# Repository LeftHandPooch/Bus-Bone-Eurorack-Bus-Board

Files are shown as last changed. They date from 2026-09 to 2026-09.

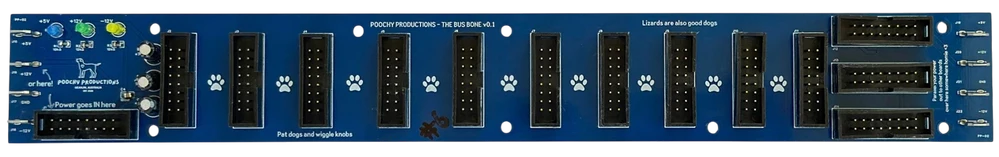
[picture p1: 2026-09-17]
PP02Hylin.webp

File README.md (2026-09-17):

# PP-02 Bus-Bone
A 14-header Eurorack passive/filtered bus-board

<p>
    
</p>

## WHY DID YOU MAKE THIS?
- Easy to build, good for practicing/learning circuit design.
- There is a great need for reliable, cheap busboards.

## WHY SHOULD I MAKE THIS?
- Aaffordable and reliable entry into the incredible world of modular.
- Ribbon cables are sketchy.
- Fully filled out supplier parts sheet so you don't have to spec anything - one-click order through JLCPCB.
- Intermediate friendly layout for those wanting to try SMD soldering.
- Lovely poochy paw prints + all the technical details on the silkscreen print.

## TECHNICAL DETAILS
- DIMENSIONS: 40mm (H) x 300mm (W) x 15mm (D)
- +12V, -12V and +5V.
- High quality PCBs with wide copper traces to accommodate high power loads.
- Spade connectors on either end to connect alternative PSUs
- Power-noise filtering caps
- 14 generously-spaced, keyed 16-pin box-headers
- Blue/Yellow/Green indicator LEDs for each power rail
- Open-source design - https://github.com/LeftHandPooch/Bus-Bone-Eurorack-Bus-Board
- Eight 3.4mm mounting holes available to mechanically secure the board to your case (3M screws/bolts and nylon washers recommended)
- Handmade in Meanjin, Australia by Brisbane’s hirsute hound, Lefthandpooch.
- 17/09/26 Built stock currently available to buy online or in-person in Brisbane @ HYLIN Devices - https://hylindevices.com.au/products/pp-02-bus-bone

## Changelog

### Bus Bone v0.1
- the original!
- drawn using EasyEda and subsequently broke the association between schematic and PCB. Darn. 
### Bus Bone v0.2
- moved components around very slightly to possibly prevent shorting of +5V rail near first header.

### Thanks and credits
My many friends and loved ones for tolerating/encouraging my passion for electronics, music and synths <3

Licensed under MIT license. 

Build and use at your own risk.

For further notes and build advice, see Basic BoM.txt

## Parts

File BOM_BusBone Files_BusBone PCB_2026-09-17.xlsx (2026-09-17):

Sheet: bom模板
 |  |  |  | Bill of Materials | BOM_BusBone Files_BusBone PCB_2026-09-17
 |  |  |  | Project Title： | PP02BusBone
 |  |  |  | Variant:
 |  |  |  | Report Time： | 2026年9月17日 13:27:15
No. | Quantity | Comment | Designator | Footprint | Value | Manufacturer Part | Manufacturer | Supplier Part | Supplier | LCSC Price | Total
 | 3 | 47uF | C1, C2, C3 | CAP-TH_BD6.3-P2.50-D1.0-FD | 47uF | ERM1HM470E11OT | AISHI(艾华集团) | C106605 | LCSC
 | 36 | 100nF | C4, C5, C6, C7, C8, C9, C10, C11, C12, C13, C14, C15, C16, C17, C18, C19, C20, C21, C22, C23, C24, C25, C26, C27, C28, C29, C30, C31, C32, C33, C34, C35, C36, C37, C38, C39 | C0805 | 100nF | CC0805KRX7R9BB104 | YAGEO(国巨) | C49678 | LCSC
 | 1 | 204-10SUGD/S400-A5 | D1 | LED-TH_BD3.0-P2.54-FD-GREEN |  | 204-10SUGD/S400-A5 | EVERLIGHT(亿光) | C99761 | LCSC
 | 1 | 204-10SURD/S530-A3-L | D2 | LED-TH_BD3.0-P2.54-FD |  | 204-10SURD/S530-A3-L | EVERLIGHT(亿光) | C99771 | LCSC
 | 1 | 204-10UYT/S530-A3 | D3 | LED-TH_BD4.0-P2.54-FD |  | 204-10UYT/S530-A3 | EVERLIGHT(亿光) | C282137 | LCSC
 | 7 | MountingHole | H1, H3, H4, H5, H6, H7, H8 | MountingHole:MountingHole_3.2mm_M3
 | 1 | MountingHole | H2 | MountingHole:MountingHole_3.2mm_M3 | MountingHole
 | 14 | BH254V-16P | J1, J2, J3, J4, J5, J6, J7, J8, J9, J10, J11, J12, J13, J14 | IDC-TH_16P-P2.54-V-R2-C8-S2.54 |  | BH254V-16P | XFCN(兴飞) | C492443 | LCSC
 | 8 | 63986-1 | J15, J16, J17, J18, J19, J20, J21, J22 | CONN-TH_63982-1 |  | 63986-1 | TE Connectivity(泰科电子) | C591345 | LCSC
 | 3 | 12kΩ | R1, R2, R3 | R0805 | 12kΩ | RC0805FR-0712KL | YAGEO(国巨) | C114556 | LCSC

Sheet: Field汇总
Project Title | PP02BusBone
Borard Title | BusBone Files
Schematic Title | BusBone Schematic
PCB Title | BusBone PCB
Variant Name
Total Quantity | 75
Report Time | 13:27:15
Report Date | 2026年9月17日
Report Date&Time | 2026年9月17日 13:27:15
File Name | BOM_BusBone Files_BusBone PCB_2026-09-17
Filter Option | Add into BOM:no;

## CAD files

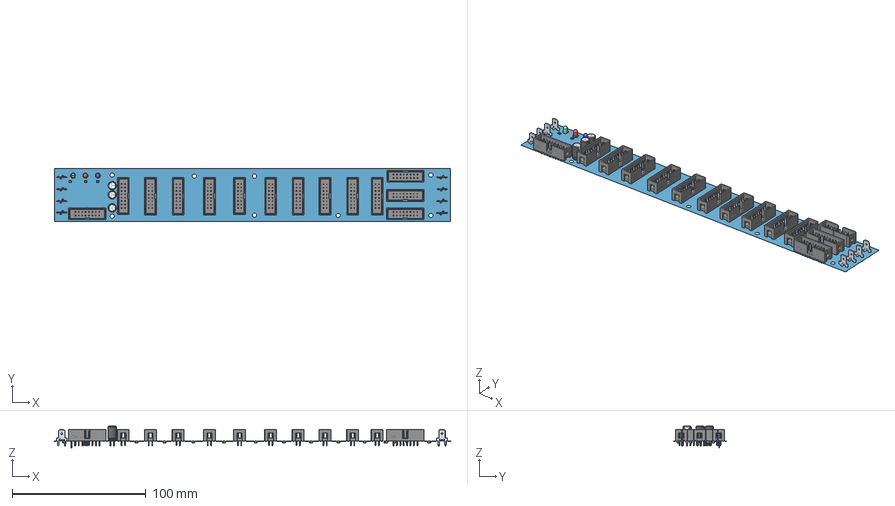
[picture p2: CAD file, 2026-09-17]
3D_BusBone PCB_2026-09-17.step
295.9 x 39.3 x 16.1 mm
Board~Zir2
TopCopper~Zir2
BottomCopper~Zir2
TopSilkscreen~Zir2
BottomSilkscreen~Zir2
TopFpcStiffener~Zir2
BottomFpcStiffener~Zir2
R0805~R0805_L2.0-W1.3-H0.6~bSlB x 3
C0805~C0805_L2.0-W1.3-H1.3~JJuE x 36
LED-TH_BD3.0-P2.54-FD~LED-TH-3mm_R~5Rdg
CAP-TH_BD6.3-P2.50-D1.0-FD~CAP-TH_BD6.3-P2.50-D1.0-FD~avoB x 3
CONN-TH_63982-1~CONN-TH_63982-1~73bF x 8
LED-TH_BD3.0-P2.54-FD-GREEN~LED-TH_BD3.0-P2.54-FD-GREEN~ZUbg
LED-TH_BD4.0-P2.54-FD~LED-TH-3mm_B~MQ57
IDC-TH_16P-P2.54-V-R2-C8-S2.54~IDC-TH_16P-P2.54-V-R2-C8-S2.54~bz8v x 14

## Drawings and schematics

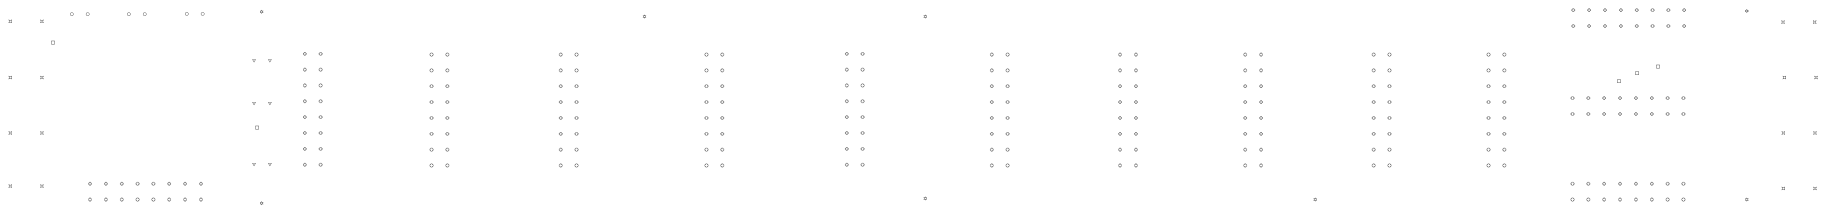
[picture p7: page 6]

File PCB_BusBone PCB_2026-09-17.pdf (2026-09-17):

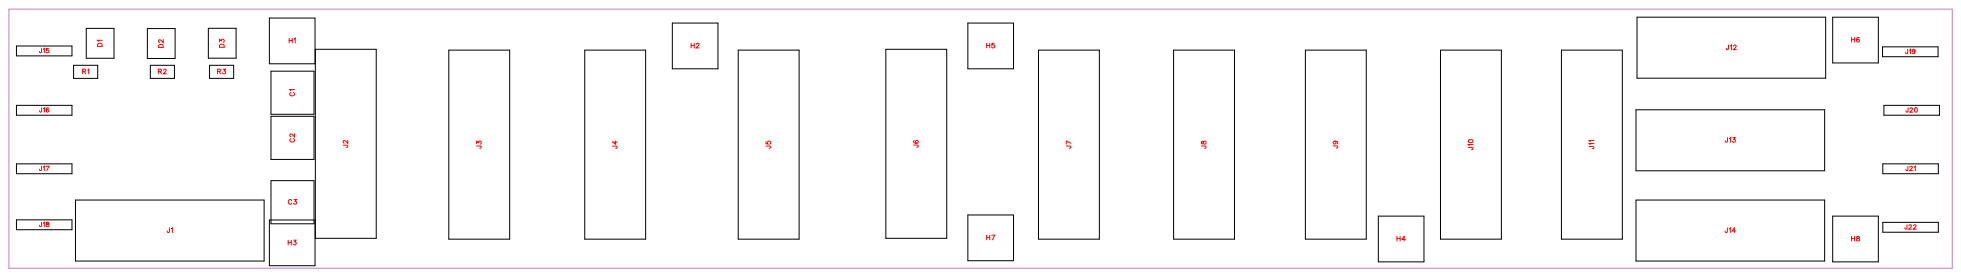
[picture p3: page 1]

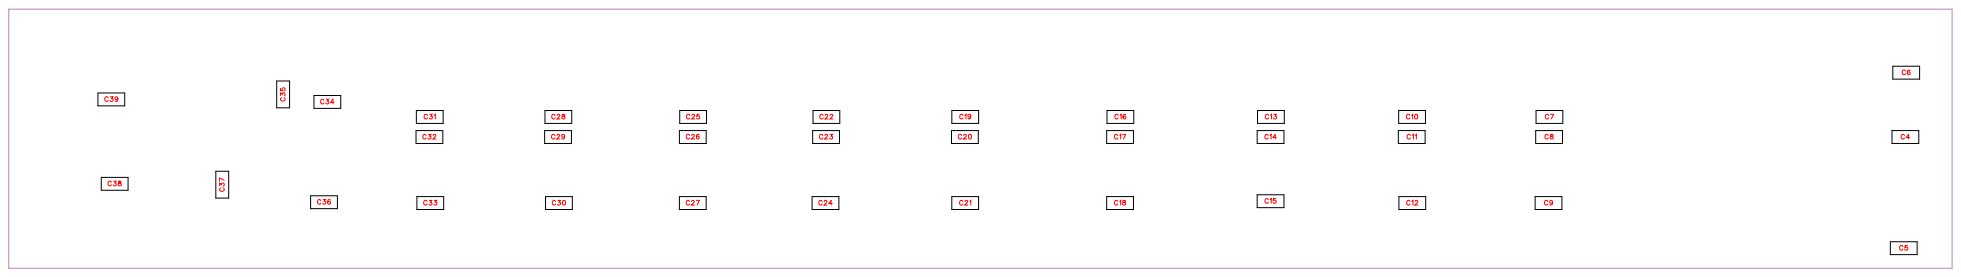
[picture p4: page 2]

No. | Quantity | Comment | Designator | Footprint | Value | Manufacturer Part | Manufacturer | Supplier Part | Supplier
1 | 3 | 47uF | C1,C2,C3 | CAP-TH_BD 6.3-P2.50-D1 .0-FD | 47uF | ERM1HM470 E11OT | AISHI(艾华集 团) | C106605 | LCSC
2 | 36 | 100nF | C4,C5,C6,C7,C8,C9,C10,C 11,C12,C13,C14,C15,C16, C17,C18,C19,C20,C21,C22 ,C23,C24,C25,C26,C27,C2 8,C29,C30,C31,C32,C33,C 34,C35,C36,C37,C38,C39 | C0805 | 100nF | CC0805KRX 7R9BB104 | YAGEO(国巨 ) | C49678 | LCSC
3 | 1 | 204-10SUGD /S400-A5 | D1 | LED-TH_BD 3.0-P2.54-FD -GREEN | | 204-10SUGD /S400-A5 | EVERLIGHT( 亿光) | C99761 | LCSC
4 | 1 | 204-10SURD /S530-A3-L | D2 | LED-TH_BD 3.0-P2.54-FD | | 204-10SURD /S530-A3-L | EVERLIGHT( 亿光) | C99771 | LCSC
5 | 1 | 204-10UYT/S 530-A3 | D3 | LED-TH_BD 4.0-P2.54-FD | | 204-10UYT/S 530-A3 | EVERLIGHT( 亿光) | C282137 | LCSC
6 | 7 | MountingHol e | H1,H3,H4,H5,H6,H7,H8 | MountingHol e:MountingH ole_3.2mm_ M3
7 | 1 | MountingHol e | H2 | MountingHol e:MountingH ole_3.2mm_ M3 | MountingHol e
8 | 14 | BH254V-16P | J1,J2,J3,J4,J5,J6,J7,J8,J9,J 10,J11,J12,J13,J14 | IDC-TH_16P-P2.54-V-R2-C8-S2.54 | | BH254V-16P | XFCN(兴飞) | C492443 | LCSC
9 | 8 | 63986-1 | J15,J16,J17,J18,J19,J20,J2 1,J22 | CONN-TH_6 3982-1 | | 63986-1 | TE Connectiv ity(泰科电子) | C591345 | LCSC
10 | 3 | 12k | R1,R2,R3 | R0805 | 12k | RC0805FR-0 712KL | YAGEO(国巨 ) | C114556 | LCSC

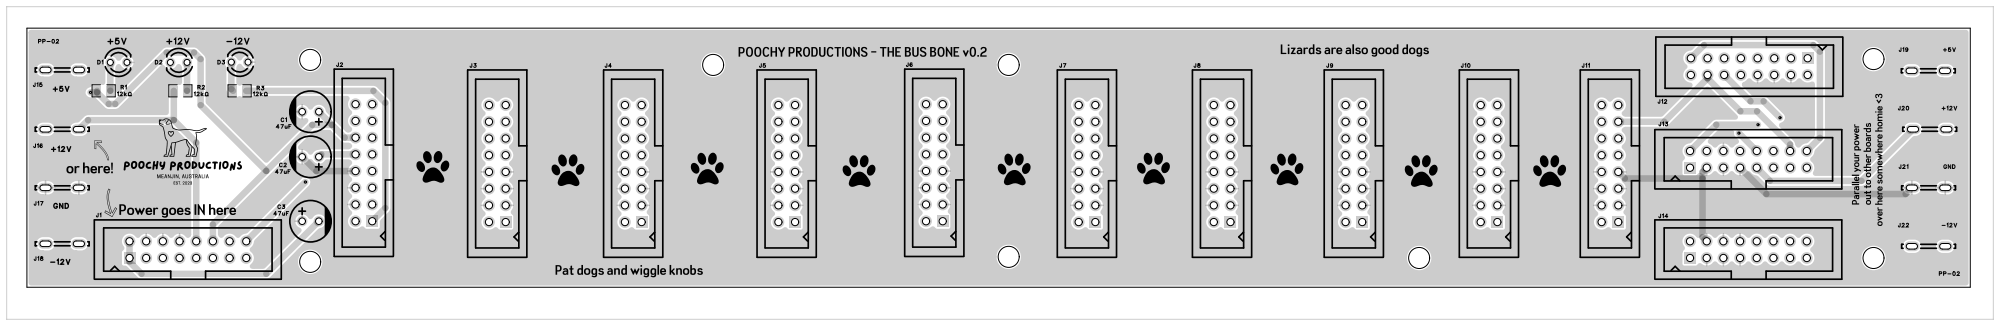
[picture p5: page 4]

Lizards are also good dogs

over here somewhere homie <3

out to other boards

Power goes IN here

Pat dogs and wiggle knobs

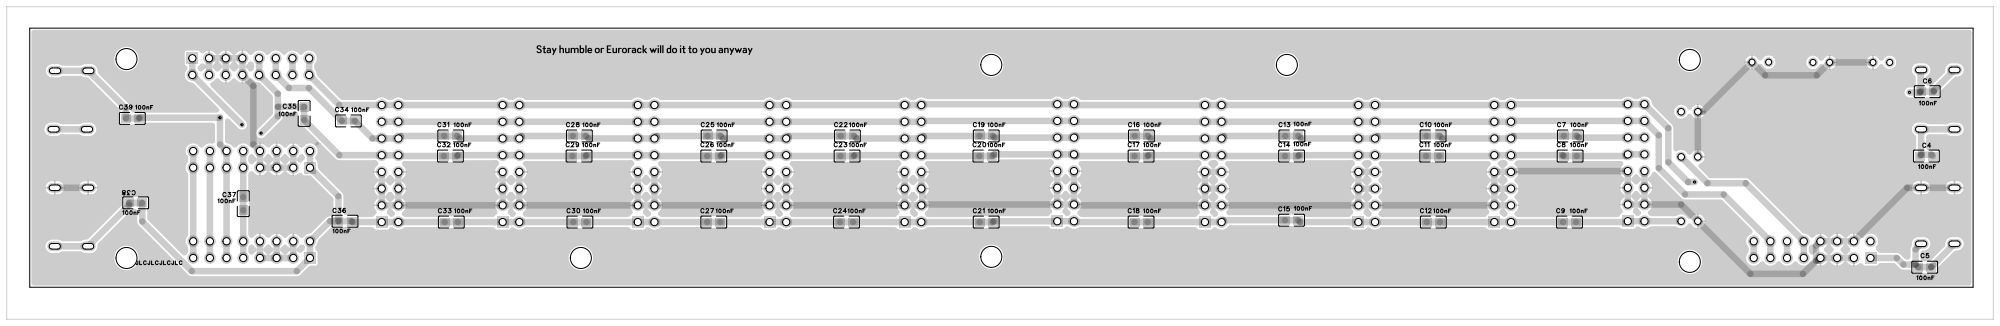
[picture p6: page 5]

Stay humble or Eurorack will do it to you anyway
